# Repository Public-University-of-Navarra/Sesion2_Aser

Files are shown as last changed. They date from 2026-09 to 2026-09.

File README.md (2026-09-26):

# Sesión 2 · Arquitectura base

Desarrollo de Equipos Electrónicos · Máster UPNA · Aser Méndez

Placa mínima: entrada de 9 V por bornas → LDO de 3,3 V → microcontrolador STM32G031K8T6 con tres entradas analógicas filtradas (RC paso bajo 1 kΩ / 100 nF, fc ≈ 1,6 kHz), una salida digital y conector SWD.

## Estructura
- Sesion2_Aser.kicad_sch (raíz): J101 (bornas 9 V) y los bloques Alimentacion y Microcontrolador.
- Alimentacion.kicad_sch: U201 MCP1703A-3302E/DB con C201 y C202.
- Microcontrolador.kicad_sch: U301 STM32G031K8T6, J301 (E/S), J302 (SWD), C301 y tres instancias de FiltroRC.kicad_sch.
- Tensiones por pines jerárquicos: VIN (raíz → Alimentacion) y 3V3 (Alimentacion → Microcontrolador). GND común.

## Selección de componentes (Mouser)
| Función | MPN | Fabricante | Motivo |
|---|---|---|---|
| MCU | STM32G031K8T6 | STMicroelectronics | Cortex-M0+, 1,7–3,6 V, LQFP-32, activo |
| LDO 3,3 V | MCP1703A-3302E/DB | Microchip | Hasta 16 V de entrada (9 V con margen), 250 mA, cerámicos de 1 µF |
| Bornas alimentación | 1715721 | Phoenix Contact | 2 polos, paso 5,08 mm |
| Conector SWD | 61300511121 | Würth Elektronik | Tira 1×5, 2,54 mm |
| Conector E/S | 61300611121 | Würth Elektronik | Tira 1×6, 2,54 mm |

## Ramas
- main: estructura e integración
- alimentacion: hoja de alimentación
- microcontrolador: hoja del MCU y BOM

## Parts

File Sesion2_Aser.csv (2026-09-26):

Reference | Qty | Value | DNP | Exclude from BOM | Exclude from Board | Exclude from Simulation | Exclude from Position Files | Footprint | Datasheet | Manufacturer | MPN
C201,C202 | 2 | 1u |  |  |  |  | ${EXCLUDE_FROM_POS_FILES} | Capacitor_SMD:C_0805_2012Metric_Pad1.18x1.45mm_HandSolder |  | Murata | GRM21BR71H105KA12L
C301,C401,C501,C601 | 4 | 100n |  |  |  |  | ${EXCLUDE_FROM_POS_FILES} | Capacitor_SMD:C_0805_2012Metric_Pad1.18x1.45mm_HandSolder |  | YAGEO | CC0805KRX7R9BB104
J101 | 1 | VIN 9V |  |  |  |  | ${EXCLUDE_FROM_POS_FILES} | TerminalBlock_Phoenix:TerminalBlock_Phoenix_MKDS-1,5-2-5.08_1x02_P5.08mm_Horizontal |  | Phoenix Contact | 1715721
J301 | 1 | SWD |  |  |  |  | ${EXCLUDE_FROM_POS_FILES} | Connector_PinHeader_2.54mm:PinHeader_1x05_P2.54mm_Vertical |  | Würth Elektronik | 61300511121
J302 | 1 | E/S |  |  |  |  | ${EXCLUDE_FROM_POS_FILES} | Connector_PinHeader_2.54mm:PinHeader_1x06_P2.54mm_Vertical |  | Würth Elektronik | 61300611121
R401,R501,R601 | 3 | 1k |  |  |  |  | ${EXCLUDE_FROM_POS_FILES} | Resistor_SMD:R_0805_2012Metric_Pad1.20x1.40mm_HandSolder |  | YAGEO | RC0805FR-071KL
U201 | 1 | MCP1703A-3302E/DB |  |  |  |  | ${EXCLUDE_FROM_POS_FILES} | Package_TO_SOT_SMD:SOT-223-3_TabPin2 | http://ww1.microchip.com/downloads/en/DeviceDoc/20005122B.pdf | Microchip | MCP1703A-3302E/DB
U301 | 1 | STM32G031K8T6 |  |  |  |  | ${EXCLUDE_FROM_POS_FILES} | Package_QFP:LQFP-32_7x7mm_P0.8mm | https://www.st.com/resource/en/datasheet/stm32g031k8.pdf | STMicroelectronics | STM32G031K8T6

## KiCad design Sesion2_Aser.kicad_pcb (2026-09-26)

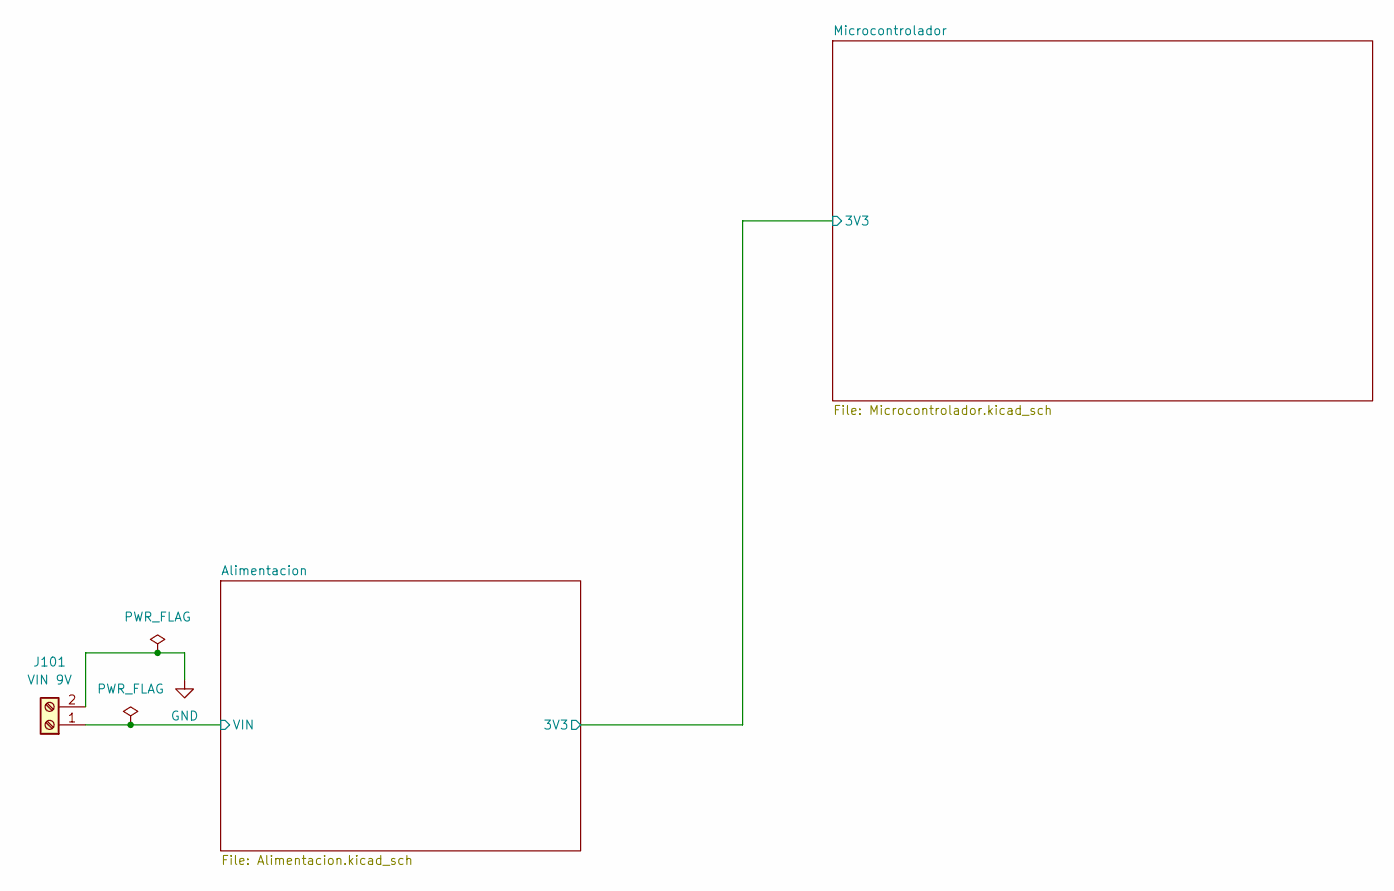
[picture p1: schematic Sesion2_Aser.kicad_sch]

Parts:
J101: VIN 9V; TerminalBlock_Phoenix_MKDS-1,5-2-5.08_1x02_P5.08mm_Horizont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; MPN 1715721

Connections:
/Alimentacion/VIN: J101.1; also elsewhere on the board
GND: J101.2; also elsewhere on the board

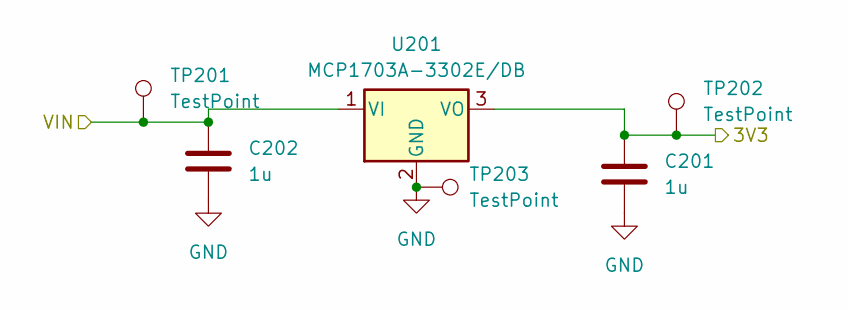
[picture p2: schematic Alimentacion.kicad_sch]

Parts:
C201, C202: 1u; C_0805_2012Metric_Pad1.18x1.45mm_HandSolder; MPN GRM21BR71H105KA12L
TP201, TP202: TestPoint; TestPoint_Keystone_5000-5004_Miniature; MPN 5000
TP203: TestPoint; TestPoint_Keystone_5000-5004_Miniature; MPN 5001
U201: MCP1703A-3302E/DB; SOT-223-3_TabPin2; MPN MCP1703A-3302E/DB

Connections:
/Alimentacion/3V3: C201.1, TP202.1 (1_1), U201.3 (VO); also elsewhere on the board
/Alimentacion/VIN: C202.1, TP201.1 (1_1), U201.1 (VI); also elsewhere on the board
GND: C201.2, C202.2, TP203.1 (1_1), U201.2 (GND); also elsewhere on the board

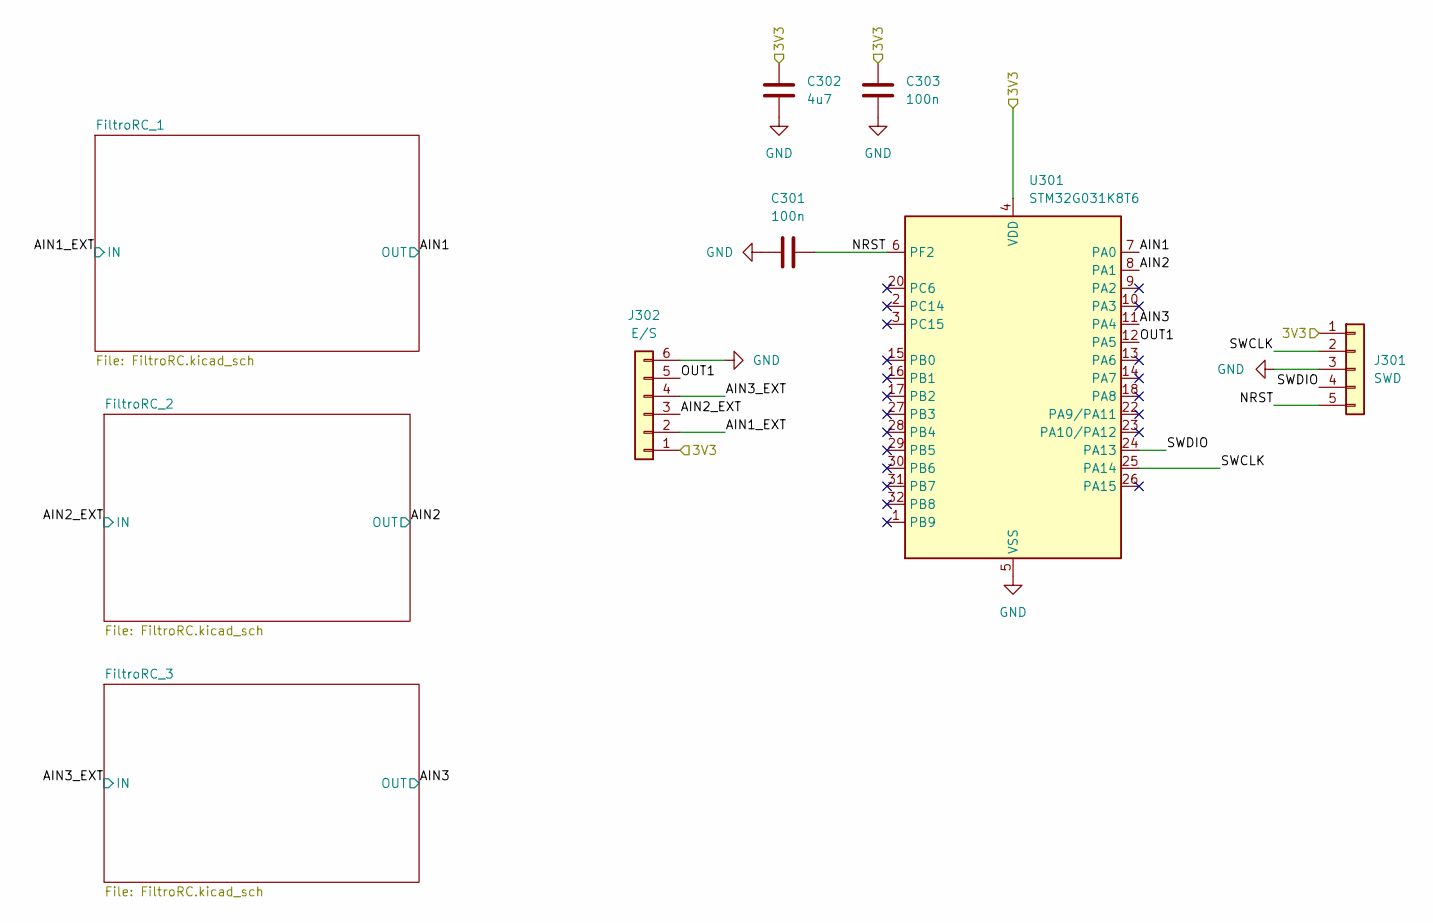
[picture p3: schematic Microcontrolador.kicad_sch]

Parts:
C301, C303: 100n; C_0805_2012Metric_Pad1.18x1.45mm_HandSolder; MPN CC0805KRX7R9BB104
C302: 4u7; C_0805_2012Metric_Pad1.18x1.45mm_HandSolder; MPN GRM21BR71E475KA73L
J301: SWD; PinHeader_1x05_P2.54mm_Vertical; MPN 61300511121
J302: E/S; PinHeader_1x06_P2.54mm_Vertical; MPN 61300611121
U301: STM32G031K8T6; LQFP-32_7x7mm_P0.8mm; MPN STM32G031K8T6

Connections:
/Alimentacion/3V3: C302.1, C303.1, J301.1, J302.1, U301.4 (VDD); also elsewhere on the board
/Microcontrolador/AIN1: U301.7 (PA0); also elsewhere on the board
/Microcontrolador/AIN1_EXT: J302.2; also elsewhere on the board
/Microcontrolador/AIN2: U301.8 (PA1); also elsewhere on the board
/Microcontrolador/AIN2_EXT: J302.3; also elsewhere on the board
/Microcontrolador/AIN3: U301.11 (PA4); also elsewhere on the board
/Microcontrolador/AIN3_EXT: J302.4; also elsewhere on the board
/Microcontrolador/NRST: C301.2, J301.5, U301.6 (PF2)
/Microcontrolador/OUT1: J302.5, U301.12 (PA5)
/Microcontrolador/SWCLK: J301.2, U301.25 (PA14)
/Microcontrolador/SWDIO: J301.4, U301.24 (PA13)
GND: C301.1, C302.2, C303.2, J301.3, J302.6, U301.5 (VSS); also elsewhere on the board

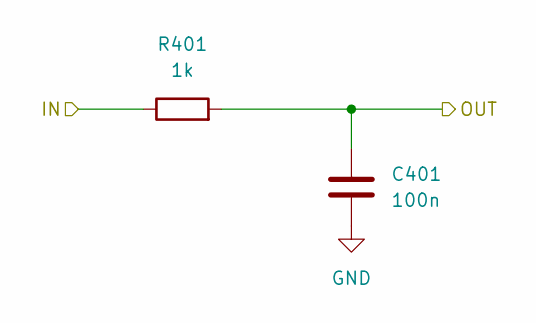
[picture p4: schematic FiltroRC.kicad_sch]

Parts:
C401: 100n; C_0805_2012Metric_Pad1.18x1.45mm_HandSolder; MPN CC0805KRX7R9BB104
R401: 1k; R_0805_2012Metric_Pad1.20x1.40mm_HandSolder; MPN RC0805FR-071KL

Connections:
/Microcontrolador/AIN1: C401.2, R401.2; also elsewhere on the board
/Microcontrolador/AIN1_EXT: R401.1; also elsewhere on the board
GND: C401.1; also elsewhere on the board

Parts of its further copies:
C501, C601: 100n; C_0805_2012Metric_Pad1.18x1.45mm_HandSolder; MPN CC0805KRX7R9BB104
R501, R601: 1k; R_0805_2012Metric_Pad1.20x1.40mm_HandSolder; MPN RC0805FR-071KL

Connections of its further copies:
/Microcontrolador/AIN2: C501.2, R501.2; also elsewhere on the board
/Microcontrolador/AIN2_EXT: R501.1; also elsewhere on the board
/Microcontrolador/AIN3: C601.2, R601.2; also elsewhere on the board
/Microcontrolador/AIN3_EXT: R601.1; also elsewhere on the board
GND: C501.1, C601.1; also elsewhere on the board

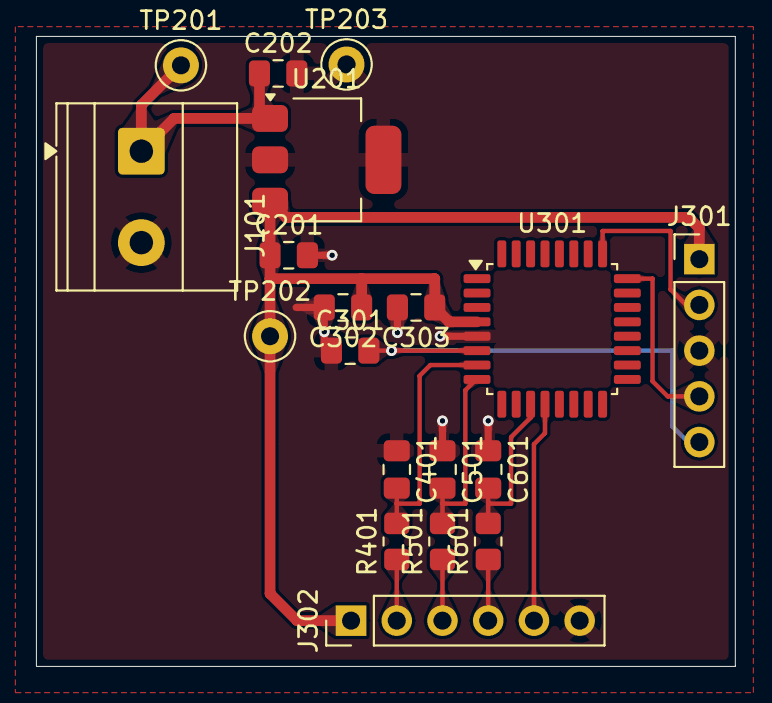
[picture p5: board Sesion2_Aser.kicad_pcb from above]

Board: 2 copper layers, 38.8 x 35.0 mm, 19 parts (0 on the bottom side), 13 nets.

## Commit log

2026-09-26 Estructura jerárquica: raíz + Alimentacion + Microcontrolador + FiltroRC x3
    [Alimentacion.kicad_sch, FiltroRC.kicad_sch, Microcontrolador.kicad_sch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]
2026-09-26 Alimentacion: J101 bornas 9 V, U201 MCP1703A 3,3 V, C201/C202 1 uF (huellas y MPN)
    [Alimentacion.kicad_sch, FiltroRC.kicad_sch, Sesion2_Aser.kicad_sch]
2026-09-26 Microcontrolador: STM32G031K8T6, SWD, conector E/S y 3 filtros RC (huellas y MPN)
    [FiltroRC.kicad_sch, Microcontrolador.kicad_sch]
2026-09-26 BOM con MPN
    [Sesion2_Aser.csv]
2026-09-26 Correcciones: huella C202, conectores J301/J302, SWD al MCU, MPN en su campo y BOM
    [Alimentacion.kicad_sch, FiltroRC.kicad_sch, Microcontrolador.kicad_sch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]
2026-09-26 Valores eléctricos en Value y BOM actualizada
    [Alimentacion.kicad_sch, FiltroRC.kicad_sch, Microcontrolador.kicad_sch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]
2026-09-26 Esquema: desacoplo de U301 (100 nF + 4,7 uF) y puntos de test VIN/3V3/GND
    [Alimentacion.kicad_sch, Microcontrolador.kicad_sch]
2026-09-26 PCB rutada, zona GND, lágrimas, DRC 0 errores
    [Sesion2_Aser.kicad_pcb]
